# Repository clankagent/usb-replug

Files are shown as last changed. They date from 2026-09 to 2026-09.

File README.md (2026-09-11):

# USB Replug — revision B

A USB-A male-to-female adapter intended to simulate unplugging and reconnecting a USB 2.0 peripheral with one button press. A CMOS 555 provides the delay; there is no microcontroller or firmware.

**Public design review. Unbuilt prototype; not ready to order.** Assembly placement mappings remain unresolved and hardware performance has not been tested. This repository contains only the current revision B source and review material, not previous design iterations or fabrication releases.

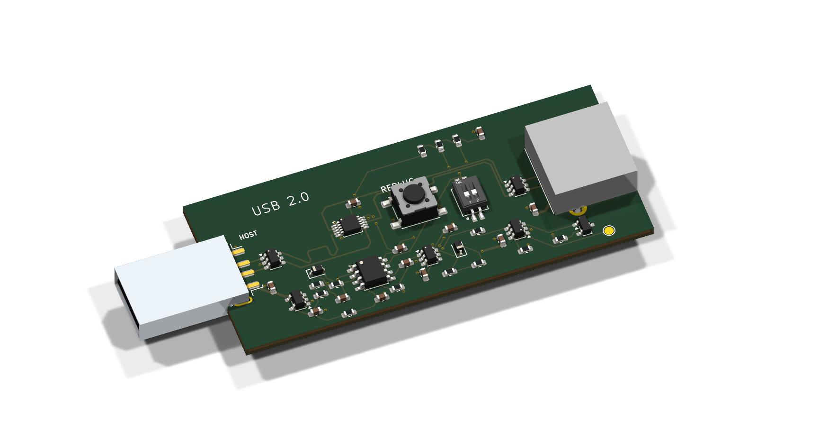
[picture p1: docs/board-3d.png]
Revision B KiCad render


[Schematic PDF](docs/schematic.pdf) · [3D STEP model](docs/usb-replug.step) · [BOM](bom.csv) · [Remaining work](docs/STATUS.md)

## Intended operation

Press the central button to disconnect device VBUS and both data lines, then reconnect automatically. Ground and shields stay connected. The trigger circuit is intended to let the timer expire even when the button remains held down.

| Two-position DIP switch | Approximate off time |
|---|---:|
| Both OFF | 3 seconds |
| Either ON | 2 seconds |
| Both ON | 1 second |

Change the DIP settings while idle. RC tolerance, leakage and capacitor bias affect timing; these are nominal settings, not calibrated delays.

## Open the design

Open `usb-replug.kicad_pro` in KiCad 10. The root schematic links three functional sheets. The PCB, footprints and referenced STEP models are included with project-relative paths. Official symbols are embedded in the schematics; the custom symbol library is under `libraries/`.

The board is 70 × 30 mm with four copper layers and nominal 1.6 mm thickness. Its fabrication target is JLC04161H-7628, outer 1 oz / inner 0.5 oz copper, green mask, white silkscreen and lead-free HASL. The male connector overhangs the PCB edge. A different manufacturer needs a stackup and assembly review.

## Validation

The packaged source was checked with KiCad 10.0.6: no reported ERC, PCB DRC, unconnected-item or schematic-parity findings. Reports and their configured ignored-check lists are included in `docs/checks/`. This is not a claim that every possible rule is enabled or that hardware works.

The intended USB data rate is up to 480 Mbps. Signal integrity, impedance, interoperability, ESD behavior, loaded voltage drop and timing still require review and physical testing. Length matching alone does not validate the USB routing; the layout includes uncoupled breakout sections. A self-powered peripheral may disconnect logically without actually power-cycling. Host power budget includes the adapter's own consumption.

## Assembly and availability

All small components are intended for factory assembly. JLCPCB's quoted Economic option excluded J1, the male connector; it has accessible surface-mount signal joints plus shell mounting joints. J2 is through-hole. The quoted Standard option included both connectors. Historical September 2026 batch estimates were $71.08 and $106.07 respectively for five PCBs with two populated, excluding shipping and tax. These are not current offers or endorsements.

Gerbers and pick-and-place files are deliberately absent: the previous assembler preview exposed rotation and connector-origin mismatches. No order-ready release has been published and no board has been ordered.

## Licensing and provenance

See [THIRD_PARTY.md](THIRD_PARTY.md). Public visibility does not grant an open-source license for the original project; no project license has been selected. Existing third-party licenses remain in effect. Provenance and redistribution permissions for the imported footprints and DIP-switch model remain unresolved; see the linked notes.

Prepared with AI-assisted design and review; the KiCad files, not an image, are the design source of truth.

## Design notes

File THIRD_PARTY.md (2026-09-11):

# Third-party material and licensing status

## Official KiCad libraries

Official embedded symbol definitions, the named official footprint libraries, and standard package STEP models come from the KiCad 10 installation. They are compiled by the KiCad community and distributed under CC-BY-SA 4.0 with the KiCad electronic-design exception. The retained [KiCad license notice](libraries/KiCad-LICENSE.md) explains the exception and the separate rules for redistributed library collections.

Sources: https://www.kicad.org/libraries/ and https://gitlab.com/kicad/libraries/

Official footprint copies use project-relative model paths. The `ReplugB` library is custom/imported material, not an official KiCad library, despite the generic description in the library table.

## Connector models

`models/Connector_USB.3dshapes/USB_A_Molex_48037-2200_Horizontal.step` is an original simplified, drawing-based model, not manufacturer-exact CAD. Reference: Molex 480372200 sales drawing, https://www.molex.com/content/dam/molex/molex-dot-com/products/automated/en-us/salesdrawingpdf/480/48037/480372200_sd.pdf

`models/ReplugB.3dshapes/Jingtuo_902-131A1011D10100.step` is an original simplified, drawing-based model. Supplier-linked CAD with a mismatched envelope was rejected. Reference: https://www.lcsc.com/product-detail/C2345.html

Both simplify contacts and stamped/internal details; do not assume full enclosure clearance or mating fidelity from the render alone.

## Imported DIP model and corrected footprints

`models/ReplugB.3dshapes/SHOUHAN_1.27-2P_TPPT.step` was imported from supplier-linked CAD and offset vertically to align with the board. Reference part: https://www.lcsc.com/product-detail/C7421516.html . A redistribution license has not been established. The two `ReplugB.pretty` footprints were imported and corrected against those manufacturers' drawings, including pad and drill dimensions. Their source licensing also needs review before public distribution.

The repository is publicly viewable, but these permissions remain unresolved. Inclusion does not establish a redistribution license. The assembled STEP export and render also include the imported model.

## Original design

No public license is selected yet for the original circuit, layout, documentation or drawing-based models. Public visibility does not waive third-party rights or grant an open-source license. Supplier datasheet PDFs and rejected/unused CAD are not bundled; use the source links and BOM references.

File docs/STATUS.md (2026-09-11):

# Review status

Revision B is a publicly viewable, unbuilt prototype snapshot. No fabrication or assembly release is approved.

## Before a prototype fabrication release

- Verify every assembler-specific rotation, pin-one/cathode orientation and placement origin. The earlier JLC preview showed timer rotation and connector position/orientation mismatches. Browser placement edits were exploratory and are not a validated CPL.
- Review USB differential routing, breakout coupling and stackup impedance. Trace length matching is insufficient.
- Review connector mechanical fit, overhang and assembly fixture requirements.
- Review component ratings, current limit, power-budget behavior and peripheral discharge/reconnect behavior against the selected BOM.
- Regenerate fabrication and placement files from the reviewed native revision; inspect the target assembler's complete preview and DFM results.

## Licensing work still unresolved

- Resolve the license of the supplier-linked SHOUHAN DIP-switch STEP model, or replace it with a newly constructed drawing-based model.
- Review provenance/licensing of the two imported, corrected `ReplugB` footprints. The manufacturer dimensions were checked, but the importer source does not by itself establish redistribution permission.
- Choose a project hardware/documentation license. Retain KiCad's library notice and applicable attribution.

## After building prototypes

Measure disconnect/reconnect timing, held-button behavior, loaded voltage drop, current limit and residual device power. Test representative USB low/full/high-speed devices and self-powered peripherals. Validate USB signal quality and protection behavior before claiming tested 480 Mbps operation or production readiness.

## Included checks

KiCad ERC and DRC/parity were rerun after copying the source into this repository. See `checks/`. The reports disclose ignored rule categories; no new suppressions were introduced for packaging.

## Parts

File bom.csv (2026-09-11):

Reference | Value | Manufacturer | MPN | LCSC | Footprint | Datasheet | Notes
J1 | USB-A PLUG | Molex | 480372200 | C2765195 | Connector_USB:USB_A_Molex_48037-2200_Horizontal | https://www.molex.com/content/dam/molex/molex-dot-com/products/automated/en-us/salesdrawingpdf/480/48037/480372200_sd.pdf | ; JLCPCB Standard assembly only. Economic variant leaves this connector unpopulated.
J2 | USB-A SOCKET | Jingtuo | 902-131A1011D10100 | C2345 | ReplugB:Jingtuo_902-131A1011D10100 | https://www.lcsc.com/datasheet/C2345.pdf | USB-A female, 1.5A/30V; 0.9mm signal drills and 2.1mm shell drills per manufacturer drawing
U1 | TPS2552DBVR | Texas Instruments | TPS2552DBVR | C46506 | Package_TO_SOT_SMD:SOT-23-6 | https://www.ti.com/lit/ds/symlink/tps2552.pdf
U2 | TLV75533PDBVR | Texas Instruments | TLV75533PDBVR | C404027 | Package_TO_SOT_SMD:SOT-23-5 | https://www.ti.com/lit/ds/symlink/tlv755p.pdf
U3 | TS3USB30EDGSR | Texas Instruments | TS3USB30EDGSR | C131998 | Package_SO:MSOP-10_3x3mm_P0.5mm | https://www.ti.com/lit/ds/symlink/ts3usb30e.pdf
U4 | TLC555CDR | Texas Instruments | TLC555CDR | C6986 | Package_SO:SOIC-8_3.9x4.9mm_P1.27mm | https://www.ti.com/lit/ds/symlink/tlc555.pdf | CMOS monostable; C6986; no firmware; approximately 1/2/3 seconds
U6 | SN74LVC2G14DBVR | Texas Instruments | SN74LVC2G14DBVR | C12401 | Package_TO_SOT_SMD:SOT-23-6 | https://www.ti.com/lit/ds/symlink/sn74lvc2g14.pdf
D1 | USBLC6-2SC6 | STMicroelectronics | USBLC6-2SC6 | C7519 | Package_TO_SOT_SMD:SOT-23-6 | https://www.st.com/resource/en/datasheet/usblc6-2.pdf
D2 | USBLC6-2SC6 | STMicroelectronics | USBLC6-2SC6 | C7519 | Package_TO_SOT_SMD:SOT-23-6 | https://www.st.com/resource/en/datasheet/usblc6-2.pdf
D3 | BAT54WS | Diodes Incorporated | BAT54WS-7-F | C124205 | Diode_SMD:D_SOD-323 | https://www.diodes.com/datasheet/download/BAT54WS.pdf | Fast RC discharge; pin 1 cathode; SOD323 two-pin package
Q1 | BSS138 | onsemi | BSS138LT1G | C82045 | Package_TO_SOT_SMD:SOT-23 | https://www.onsemi.com/pdf/datasheet/bss138lt1-d.pdf
SW1 | REPLUG | C&K | PTS645SM43SMTR92 LFS | C221880 | Button_Switch_SMD:SW_SPST_PTS645Sx43SMTR92 | https://www.ckswitches.com/media/1471/pts645.pdf
SW2 | DELAY SELECT | SHOUHAN | 1.27-2P TPPT | C7421516 | ReplugB:SHOUHAN_1.27-2P_TPPT | https://www.lcsc.com/datasheet/C7421516.pdf | 24V 25mA. Switch only while idle. OFF/OFF ~3s; one ON ~2s; both ON ~1s.
R1 | 45.3k | Yageo | RC0603FR-0745K3L | C245971 | Resistor_SMD:R_0603_1608Metric | https://www.yageo.com/upload/media/product/productsearch/datasheet/rchip/PYu-RC_Group_51_RoHS_L_12.pdf | Current limit approx 0.57 A; intended device load <=500mA with host budget respected
R2 | 100k | UNI-ROYAL | 0603WAF1003T5E | C25803 | Resistor_SMD:R_0603_1608Metric | https://www.lcsc.com/datasheet/C25803.pdf | 1%, 0.1 W, 0603
R3 | 100k | UNI-ROYAL | 0603WAF1003T5E | C25803 | Resistor_SMD:R_0603_1608Metric | https://www.lcsc.com/datasheet/C25803.pdf | 1%, 0.1 W, 0603
R4 | 1k | UNI-ROYAL | 0603WAF1001T5E | C21190 | Resistor_SMD:R_0603_1608Metric | https://www.lcsc.com/datasheet/C21190.pdf | Limits trigger clamp current
R5 | 1M | UNI-ROYAL | 0603WAF1004T5E | C22935 | Resistor_SMD:R_0603_1608Metric | https://www.lcsc.com/datasheet/C22935.pdf | 1%, 0603; t nominal = ln(3) RC; timing accuracy intentionally approximate
R6 | 1M | UNI-ROYAL | 0603WAF1004T5E | C22935 | Resistor_SMD:R_0603_1608Metric | https://www.lcsc.com/datasheet/C22935.pdf | 1%, 0603; t nominal = ln(3) RC; timing accuracy intentionally approximate
R7 | 1M | UNI-ROYAL | 0603WAF1004T5E | C22935 | Resistor_SMD:R_0603_1608Metric | https://www.lcsc.com/datasheet/C22935.pdf | 1%, 0603; t nominal = ln(3) RC; timing accuracy intentionally approximate
R8 | 100k | UNI-ROYAL | 0603WAF1003T5E | C25803 | Resistor_SMD:R_0603_1608Metric | https://www.lcsc.com/datasheet/C25803.pdf | Power-on reset pull-up
R9 | 100k | UNI-ROYAL | 0603WAF1003T5E | C25803 | Resistor_SMD:R_0603_1608Metric | https://www.lcsc.com/datasheet/C25803.pdf | Button pull-up
R15 | 47k | UNI-ROYAL | 0603WAF4702T5E | C25819 | Resistor_SMD:R_0603_1608Metric | https://www.lcsc.com/datasheet/C25819.pdf | 1%, 0.1 W, 0603
R16 | 1k | UNI-ROYAL | 0603WAF1001T5E | C21190 | Resistor_SMD:R_0603_1608Metric | https://www.lcsc.com/datasheet/C21190.pdf | 1%, 0.1 W, 0603
R17 | 1k | UNI-ROYAL | 0603WAF1001T5E | C21190 | Resistor_SMD:R_0603_1608Metric | https://www.lcsc.com/datasheet/C21190.pdf | 1%, 0.1 W, 0603
R18 | 100k | UNI-ROYAL | 0603WAF1003T5E | C25803 | Resistor_SMD:R_0603_1608Metric | https://www.lcsc.com/datasheet/C25803.pdf | 1%, 0.1 W, 0603
C1 | 1uF | Samsung Electro-Mechanics | CL10A105KB8NNNC | C15849 | Capacitor_SMD:C_0603_1608Metric | https://www.lcsc.com/datasheet/C15849.pdf | X7R, 16V, 0603; 1uF and 100nF bypass capacitors; 50V, +/-10%, X5R; supplier Basic part
C2 | 1uF | Samsung Electro-Mechanics | CL10A105KB8NNNC | C15849 | Capacitor_SMD:C_0603_1608Metric | https://www.lcsc.com/datasheet/C15849.pdf | X7R, 16V, 0603; 1uF and 100nF bypass capacitors; 50V, +/-10%, X5R; supplier Basic part
C3 | 1uF | Samsung Electro-Mechanics | CL10A105KB8NNNC | C15849 | Capacitor_SMD:C_0603_1608Metric | https://www.lcsc.com/datasheet/C15849.pdf | X7R, 16V, 0603; 1uF and 100nF bypass capacitors; 50V, +/-10%, X5R; supplier Basic part
C4 | 100nF | YAGEO | CC0603KRX7R9BB104 | C14663 | Capacitor_SMD:C_0603_1608Metric | https://www.lcsc.com/datasheet/C14663.pdf | X7R, 16V, 0603; 1uF and 100nF bypass capacitors; 50V, +/-10%, X7R; supplier Basic part
C5 | 100nF | YAGEO | CC0603KRX7R9BB104 | C14663 | Capacitor_SMD:C_0603_1608Metric | https://www.lcsc.com/datasheet/C14663.pdf | X7R, 16V, 0603; 1uF and 100nF bypass capacitors; 50V, +/-10%, X7R; supplier Basic part
C6 | 100nF | YAGEO | CC0603KRX7R9BB104 | C14663 | Capacitor_SMD:C_0603_1608Metric | https://www.lcsc.com/datasheet/C14663.pdf | X7R, 16V, 0603; 1uF and 100nF bypass capacitors; 50V, +/-10%, X7R; supplier Basic part
C7 | 100nF | YAGEO | CC0603KRX7R9BB104 | C14663 | Capacitor_SMD:C_0603_1608Metric | https://www.lcsc.com/datasheet/C14663.pdf | 555 control-voltage bypass; 50V, +/-10%, X7R; supplier Basic part
C8 | 100nF | YAGEO | CC0603KRX7R9BB104 | C14663 | Capacitor_SMD:C_0603_1608Metric | https://www.lcsc.com/datasheet/C14663.pdf | X7R, 16V, 0603; 1uF and 100nF bypass capacitors; 50V, +/-10%, X7R; supplier Basic part
C9 | 100nF | YAGEO | CC0603KRX7R9BB104 | C14663 | Capacitor_SMD:C_0603_1608Metric | https://www.lcsc.com/datasheet/C14663.pdf | AC-coupled falling-edge trigger: reconnects even with button held; 50V, +/-10%, X7R; supplier Basic part
C10 | 1uF | Samsung Electro-Mechanics | CL10A105KB8NNNC | C15849 | Capacitor_SMD:C_0603_1608Metric | https://www.lcsc.com/datasheet/C15849.pdf | X7R, 16V, 0603; 1uF and 100nF bypass capacitors; 50V, +/-10%, X5R; supplier Basic part
TP1 | FAULT_N | PCB | PCB pad |  | TestPoint:TestPoint_Pad_D1.5mm |  | Diagnostic pad; no purchased component
C11 | 1uF | Samsung Electro-Mechanics | CL10A105KB8NNNC | C15849 | Capacitor_SMD:C_0603_1608Metric | https://www.lcsc.com/datasheet/C15849.pdf | 1uF X5R 50V; nominal capacitance changes with DC bias and temperature; 50V, +/-10%, X5R; supplier Basic part
C12 | 1uF | Samsung Electro-Mechanics | CL10A105KB8NNNC | C15849 | Capacitor_SMD:C_0603_1608Metric | https://www.lcsc.com/datasheet/C15849.pdf | 1uF X5R 50V; nominal capacitance changes with DC bias and temperature; 50V, +/-10%, X5R; supplier Basic part
D4 | BAT54WS | Diodes Incorporated | BAT54WS-7-F | C124205 | Diode_SMD:D_SOD-323 | https://www.diodes.com/datasheet/download/BAT54WS.pdf | Positive trigger clamp on button release; cathode at V3V3

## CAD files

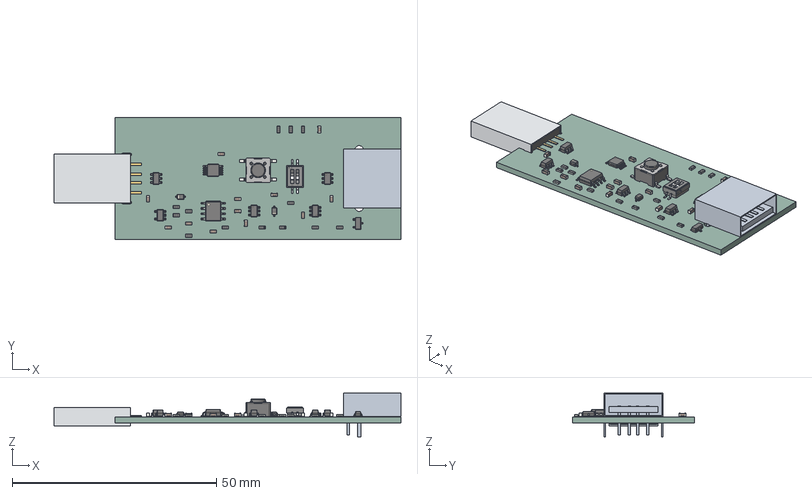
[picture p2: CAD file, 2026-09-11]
docs/usb-replug.step
85.0 x 30.0 x 10.7 mm
R_0603_1608Metric x 13
D_SOD-323 x 2
SOT-23-6 x 4
MSOP-10_3x3mm_P0.5mm
SOT-23
C_0603_1608Metric x 12
Nickel_shell
Insulator
Contact_1
Contact_2
Contact_3
Contact_4
Peg_-2.25
Peg_2.25
SOT-23-5
SOIC-8_3.9x4.9mm_P1.27mm
SW_SPST_PTS645Sx43SMTR92
SW-SMD_2P-L5.4-W4.1-P1.27-LS8.4
usb-replug_PCB

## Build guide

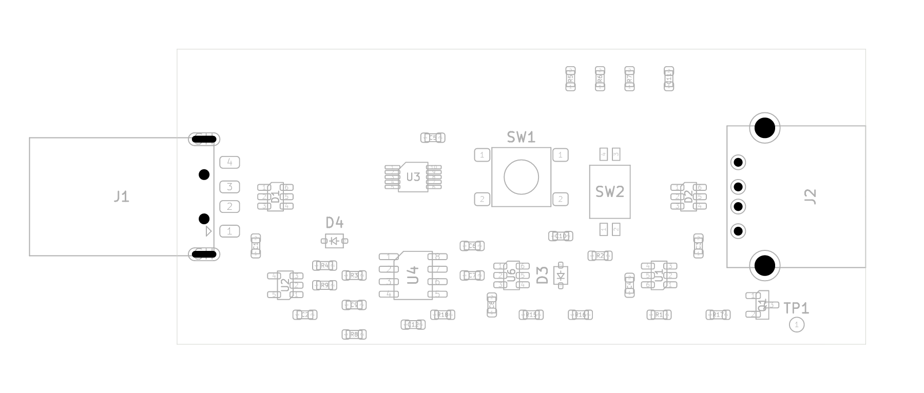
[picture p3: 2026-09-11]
docs/assembly-top.png

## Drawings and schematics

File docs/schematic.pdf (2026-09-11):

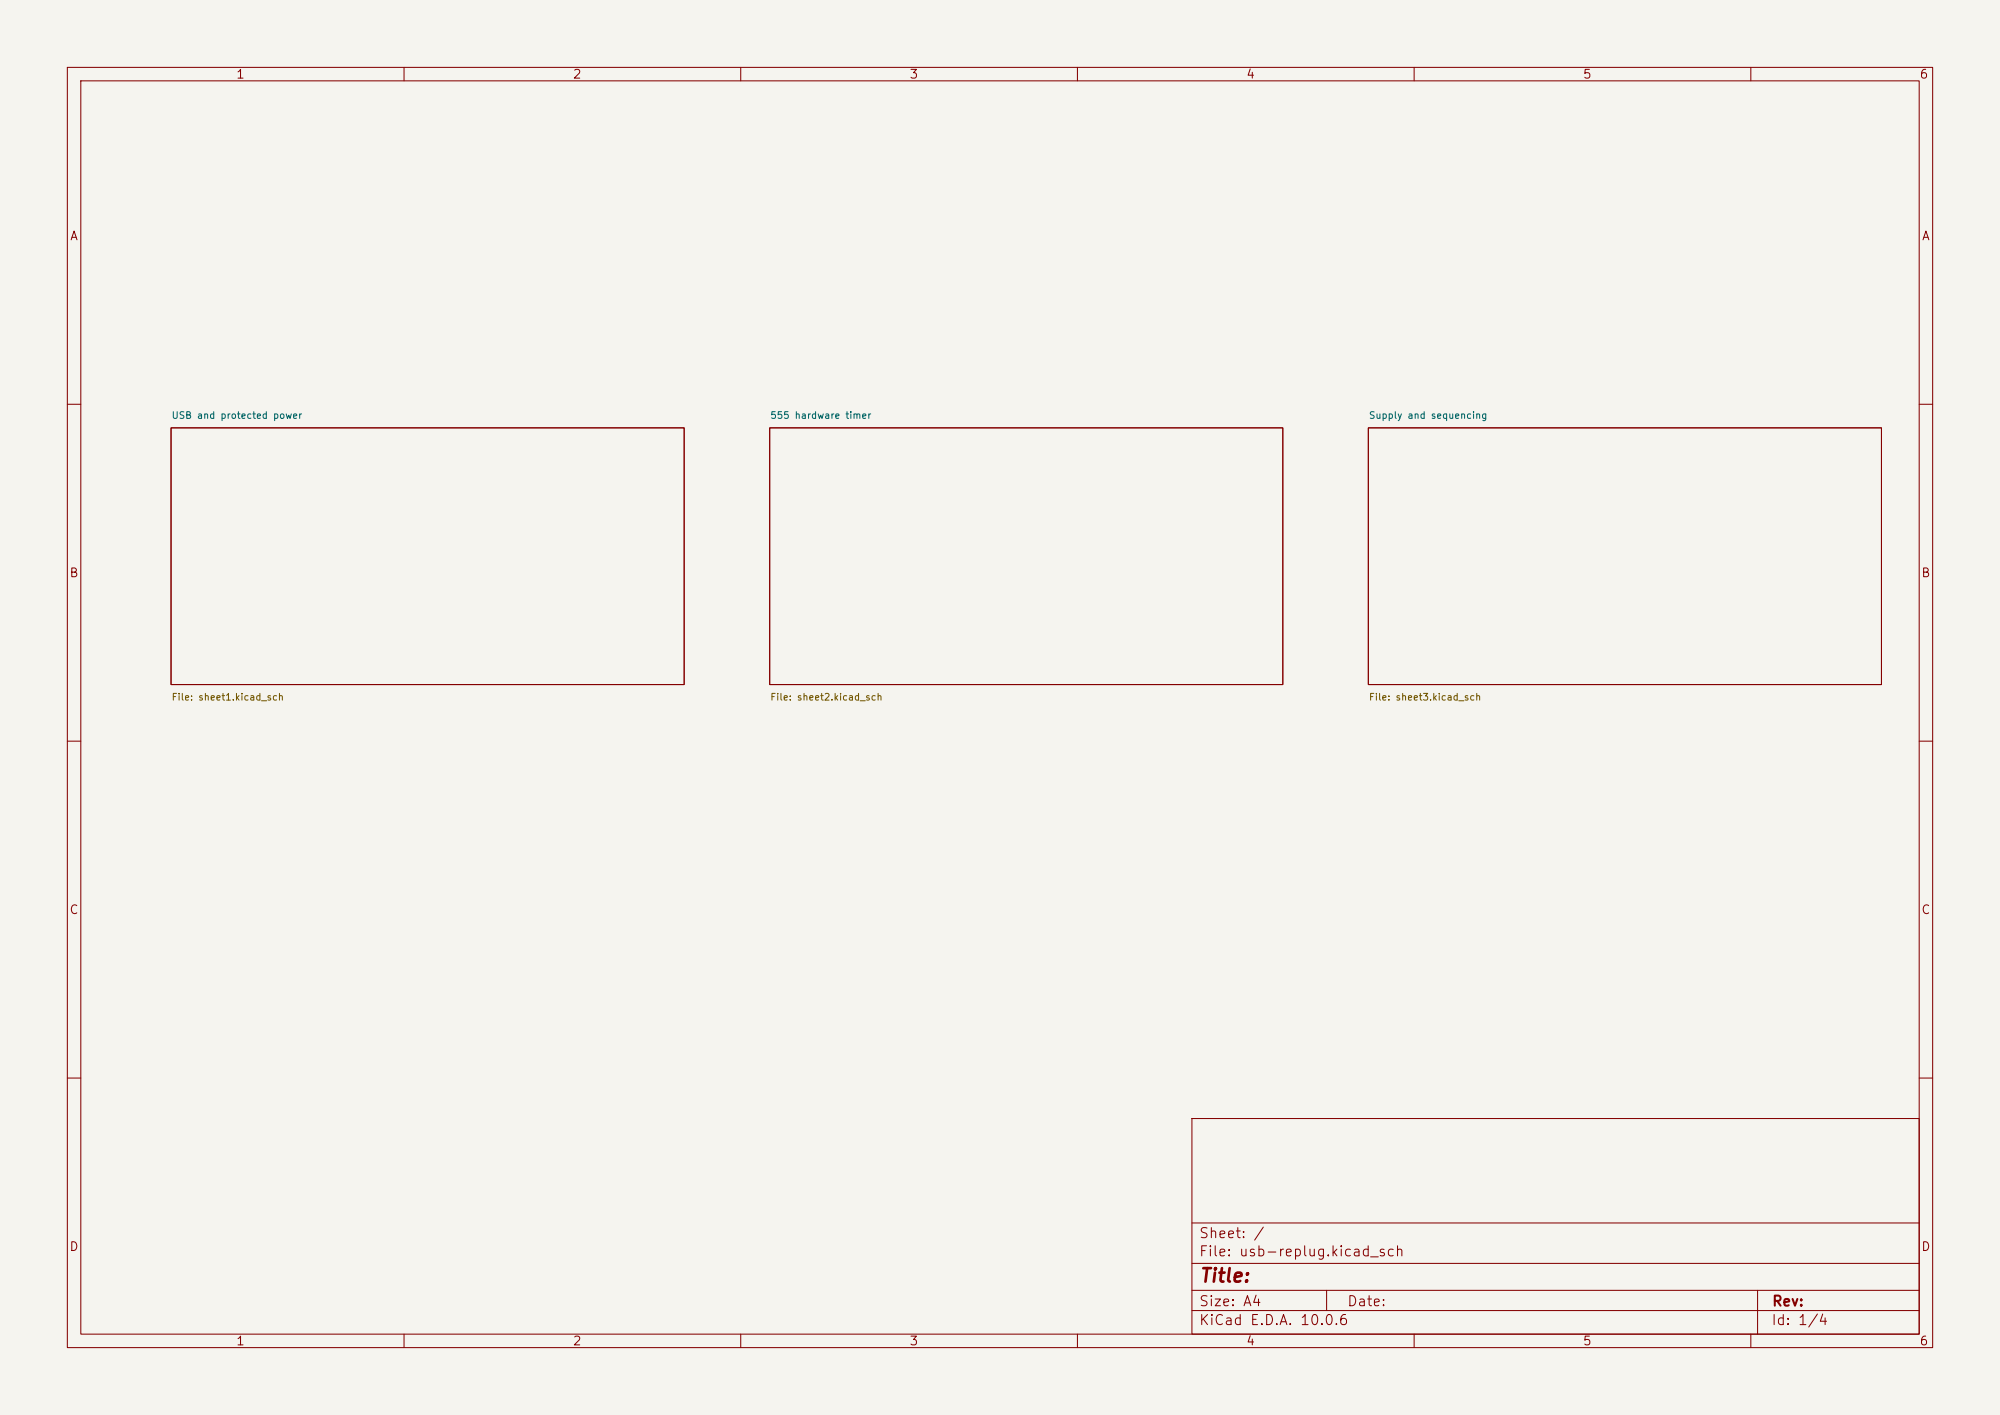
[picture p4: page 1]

Size: A4 | Rev:
KiCad E.D.A. 10.0.6 | Id: 1/4

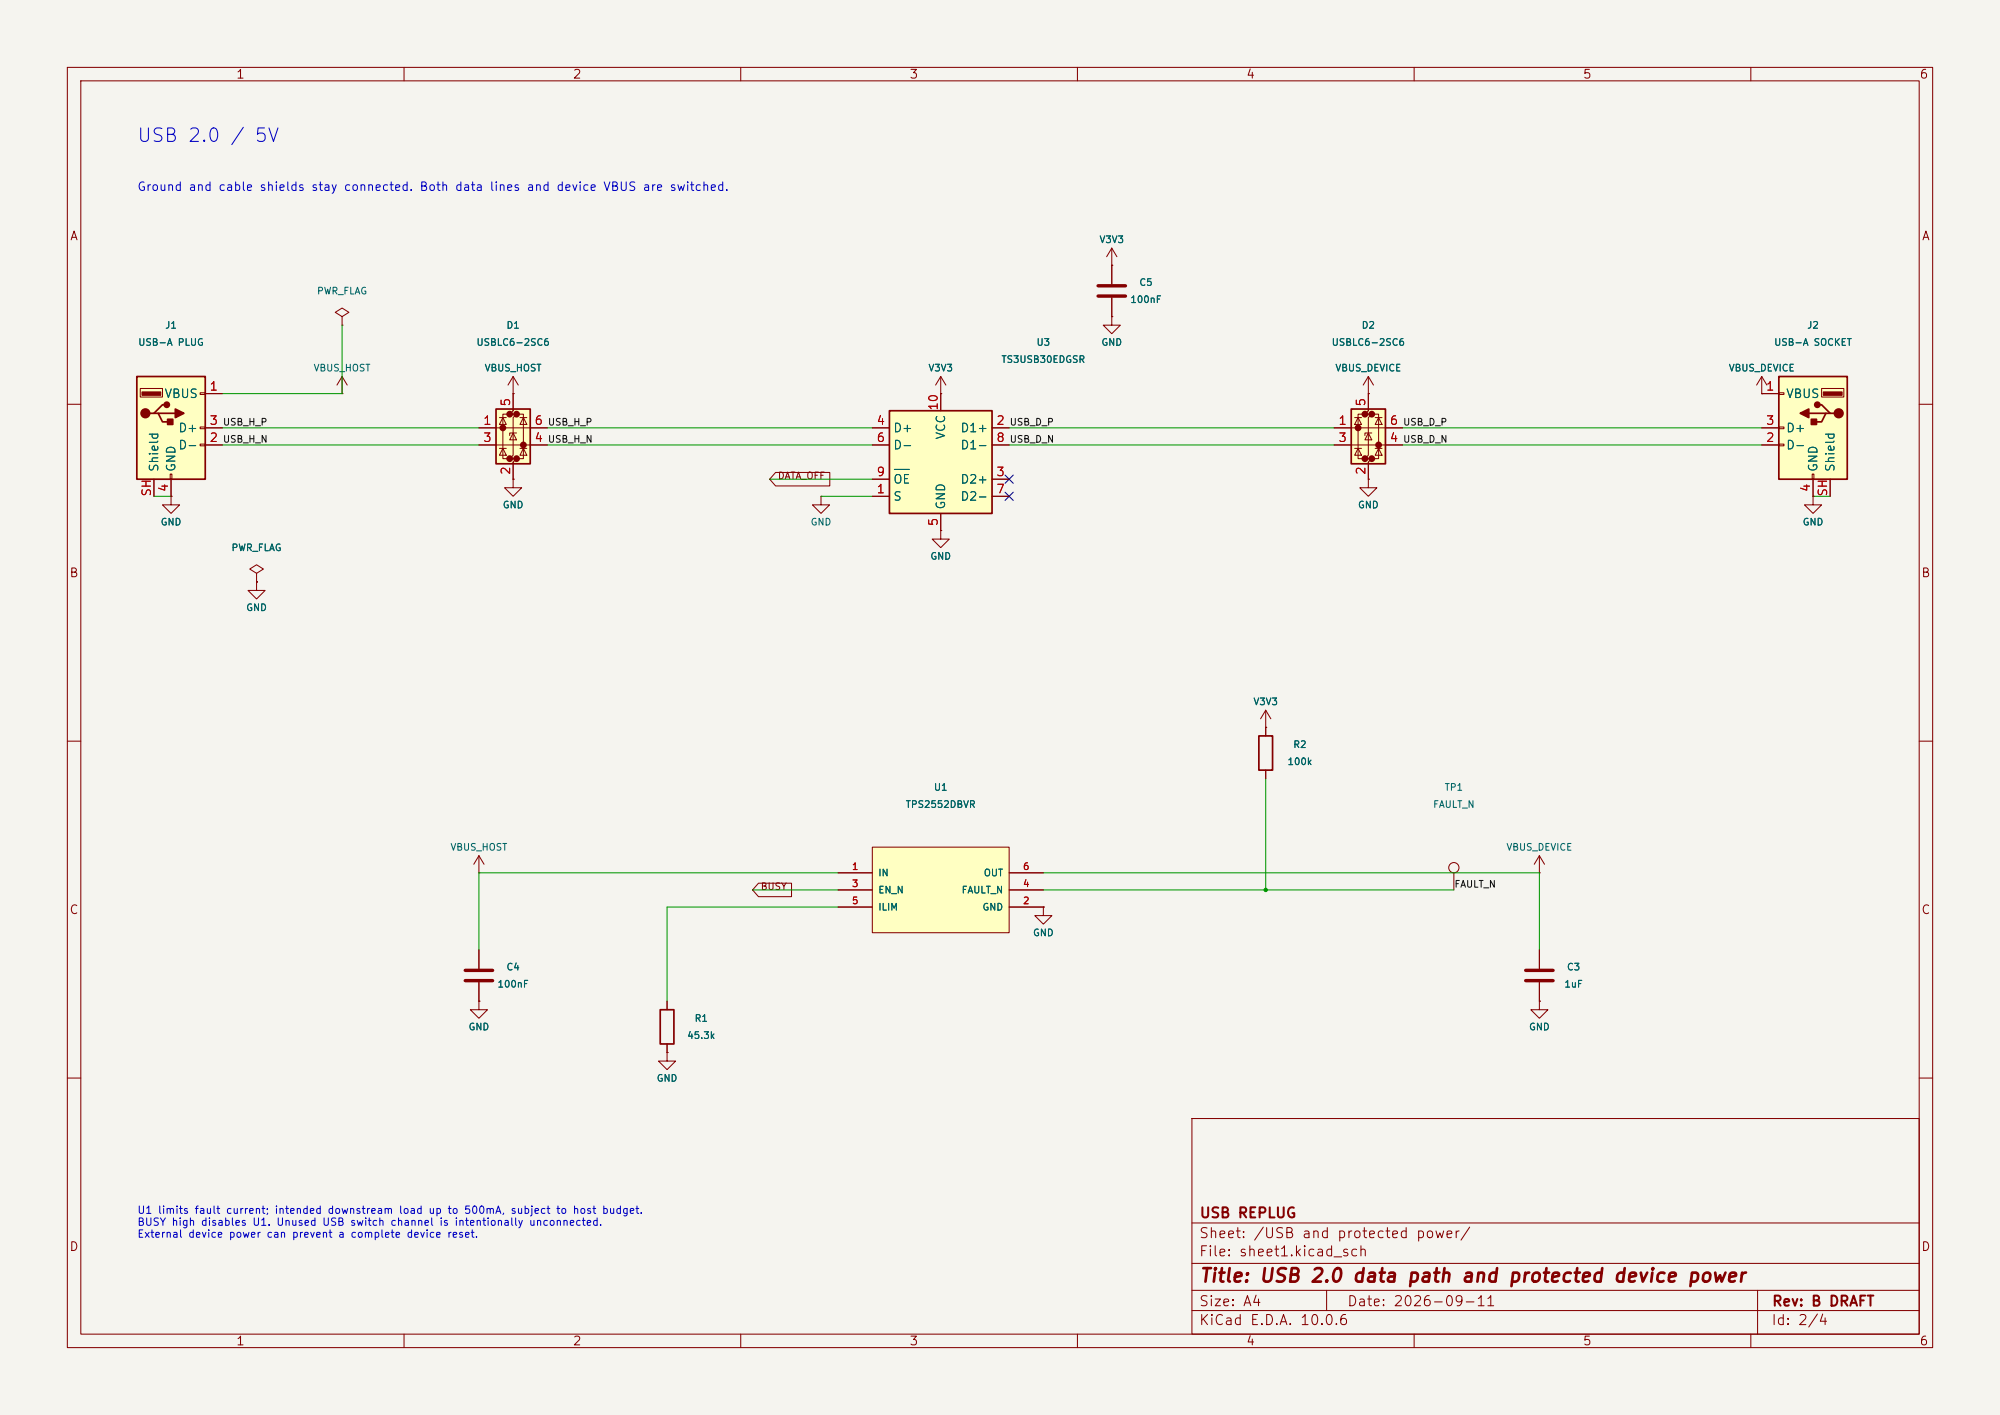
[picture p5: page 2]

Ground and cable shields stay connected. Both data lines and device VBUS are switched.

U1 limits fault current; intended downstream load up to 500mA, subject to host budget. BUSY high disables U1. Unused USB switch channel is intentionally unconnected. External device power can prevent a complete device reset.

USB REPLUG
Sheet: /USB and protected power/
File: sheet1.kicad_sch
Title: USB 2.0 data path and protected device power

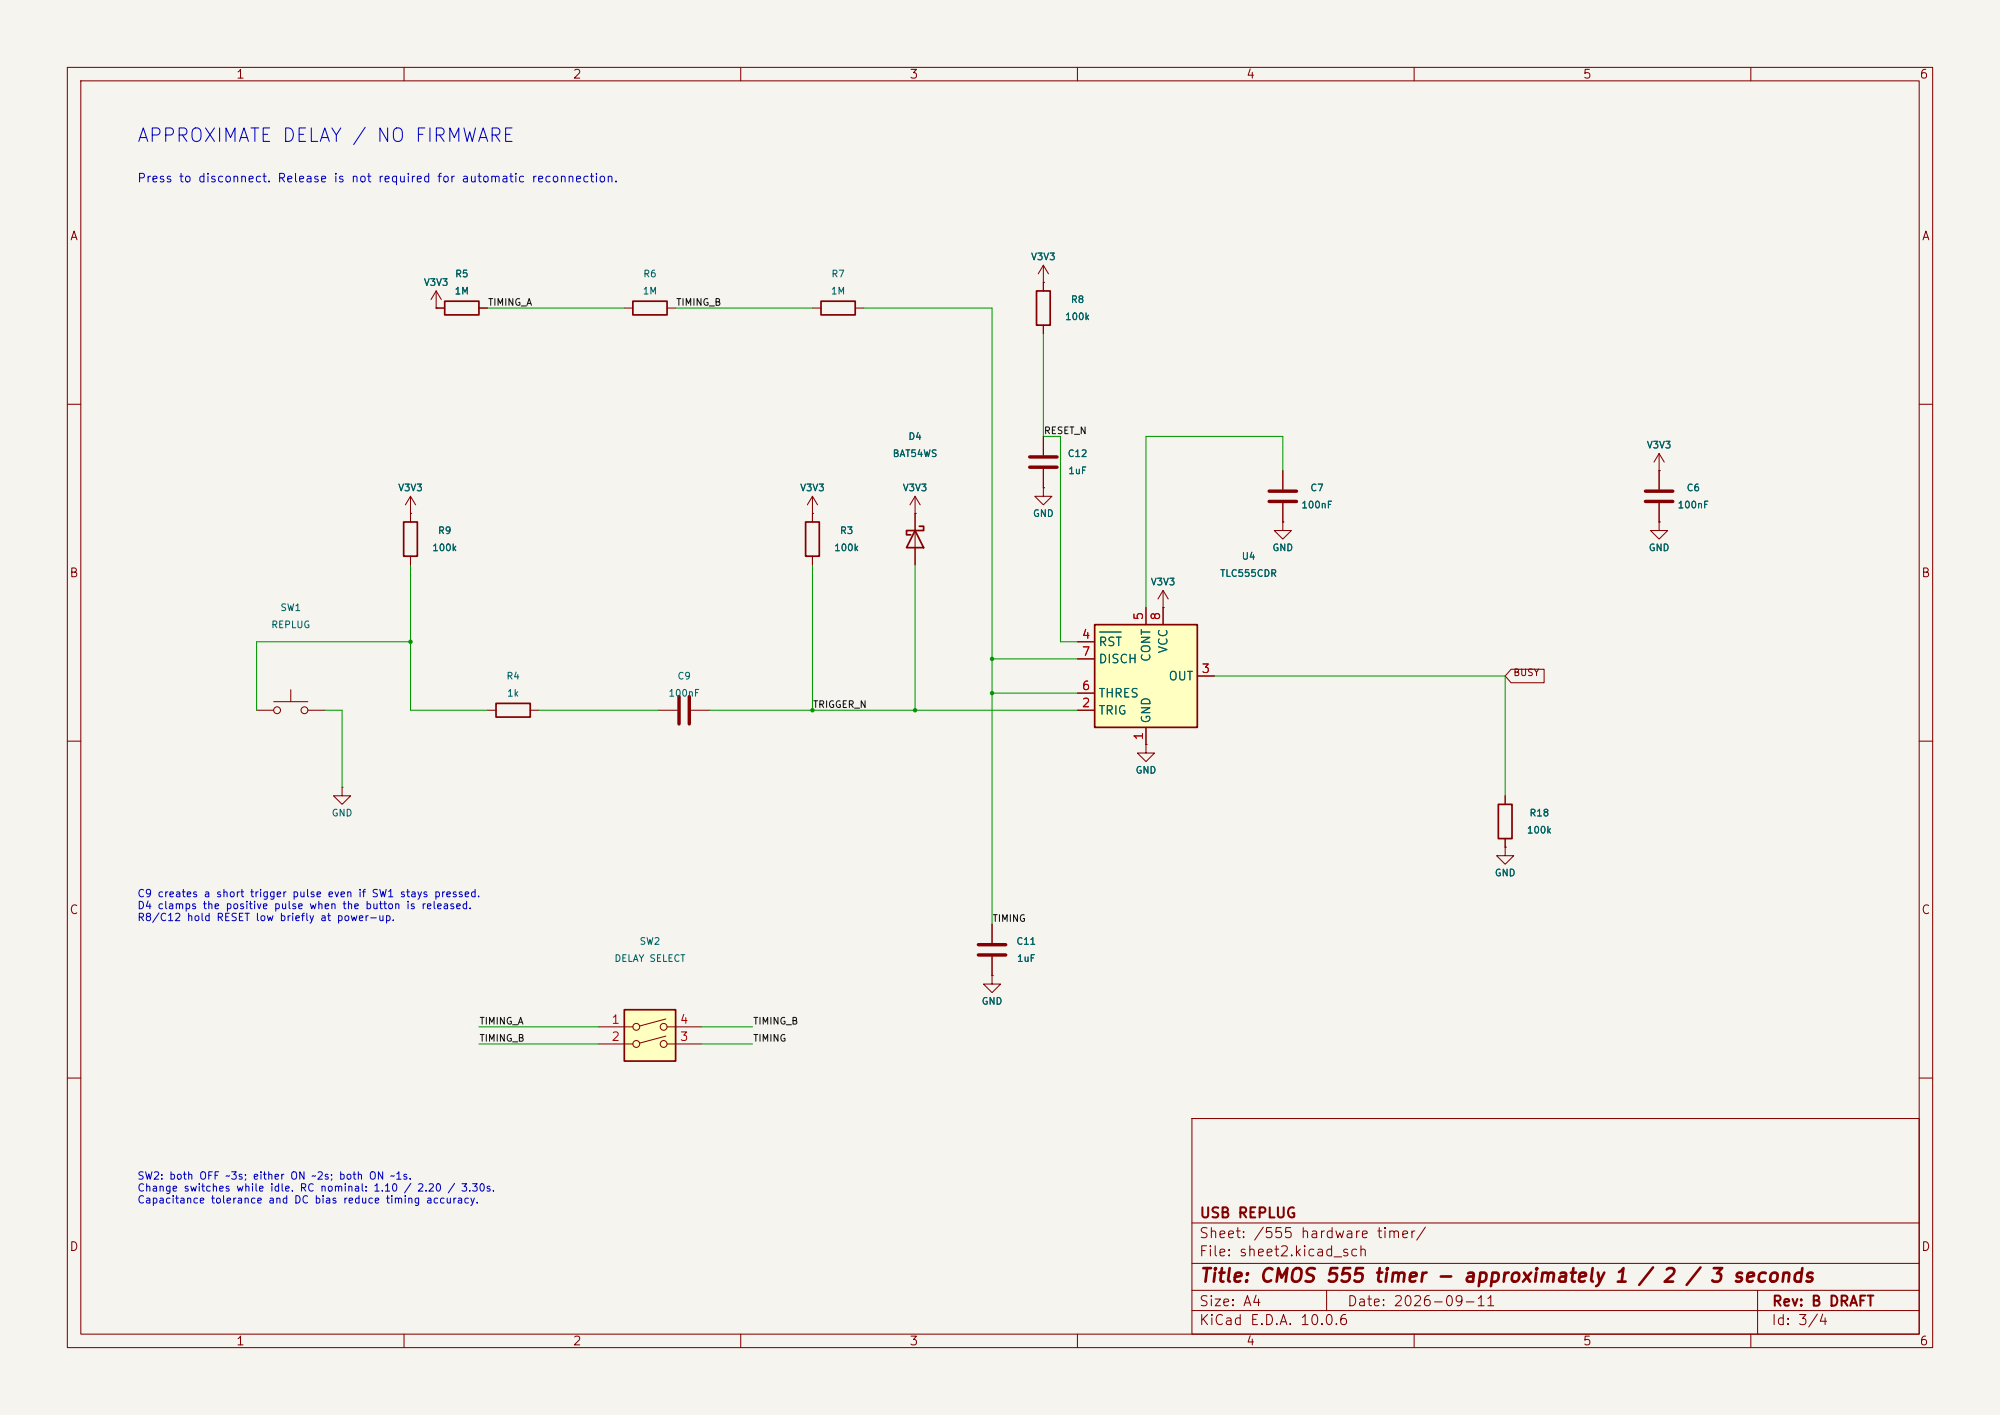
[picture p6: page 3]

USB REPLUG
Sheet: /555 hardware timer/
File: sheet2.kicad_sch
Title: CMOS 555 timer - approximately 1 / 2 / 3 seconds

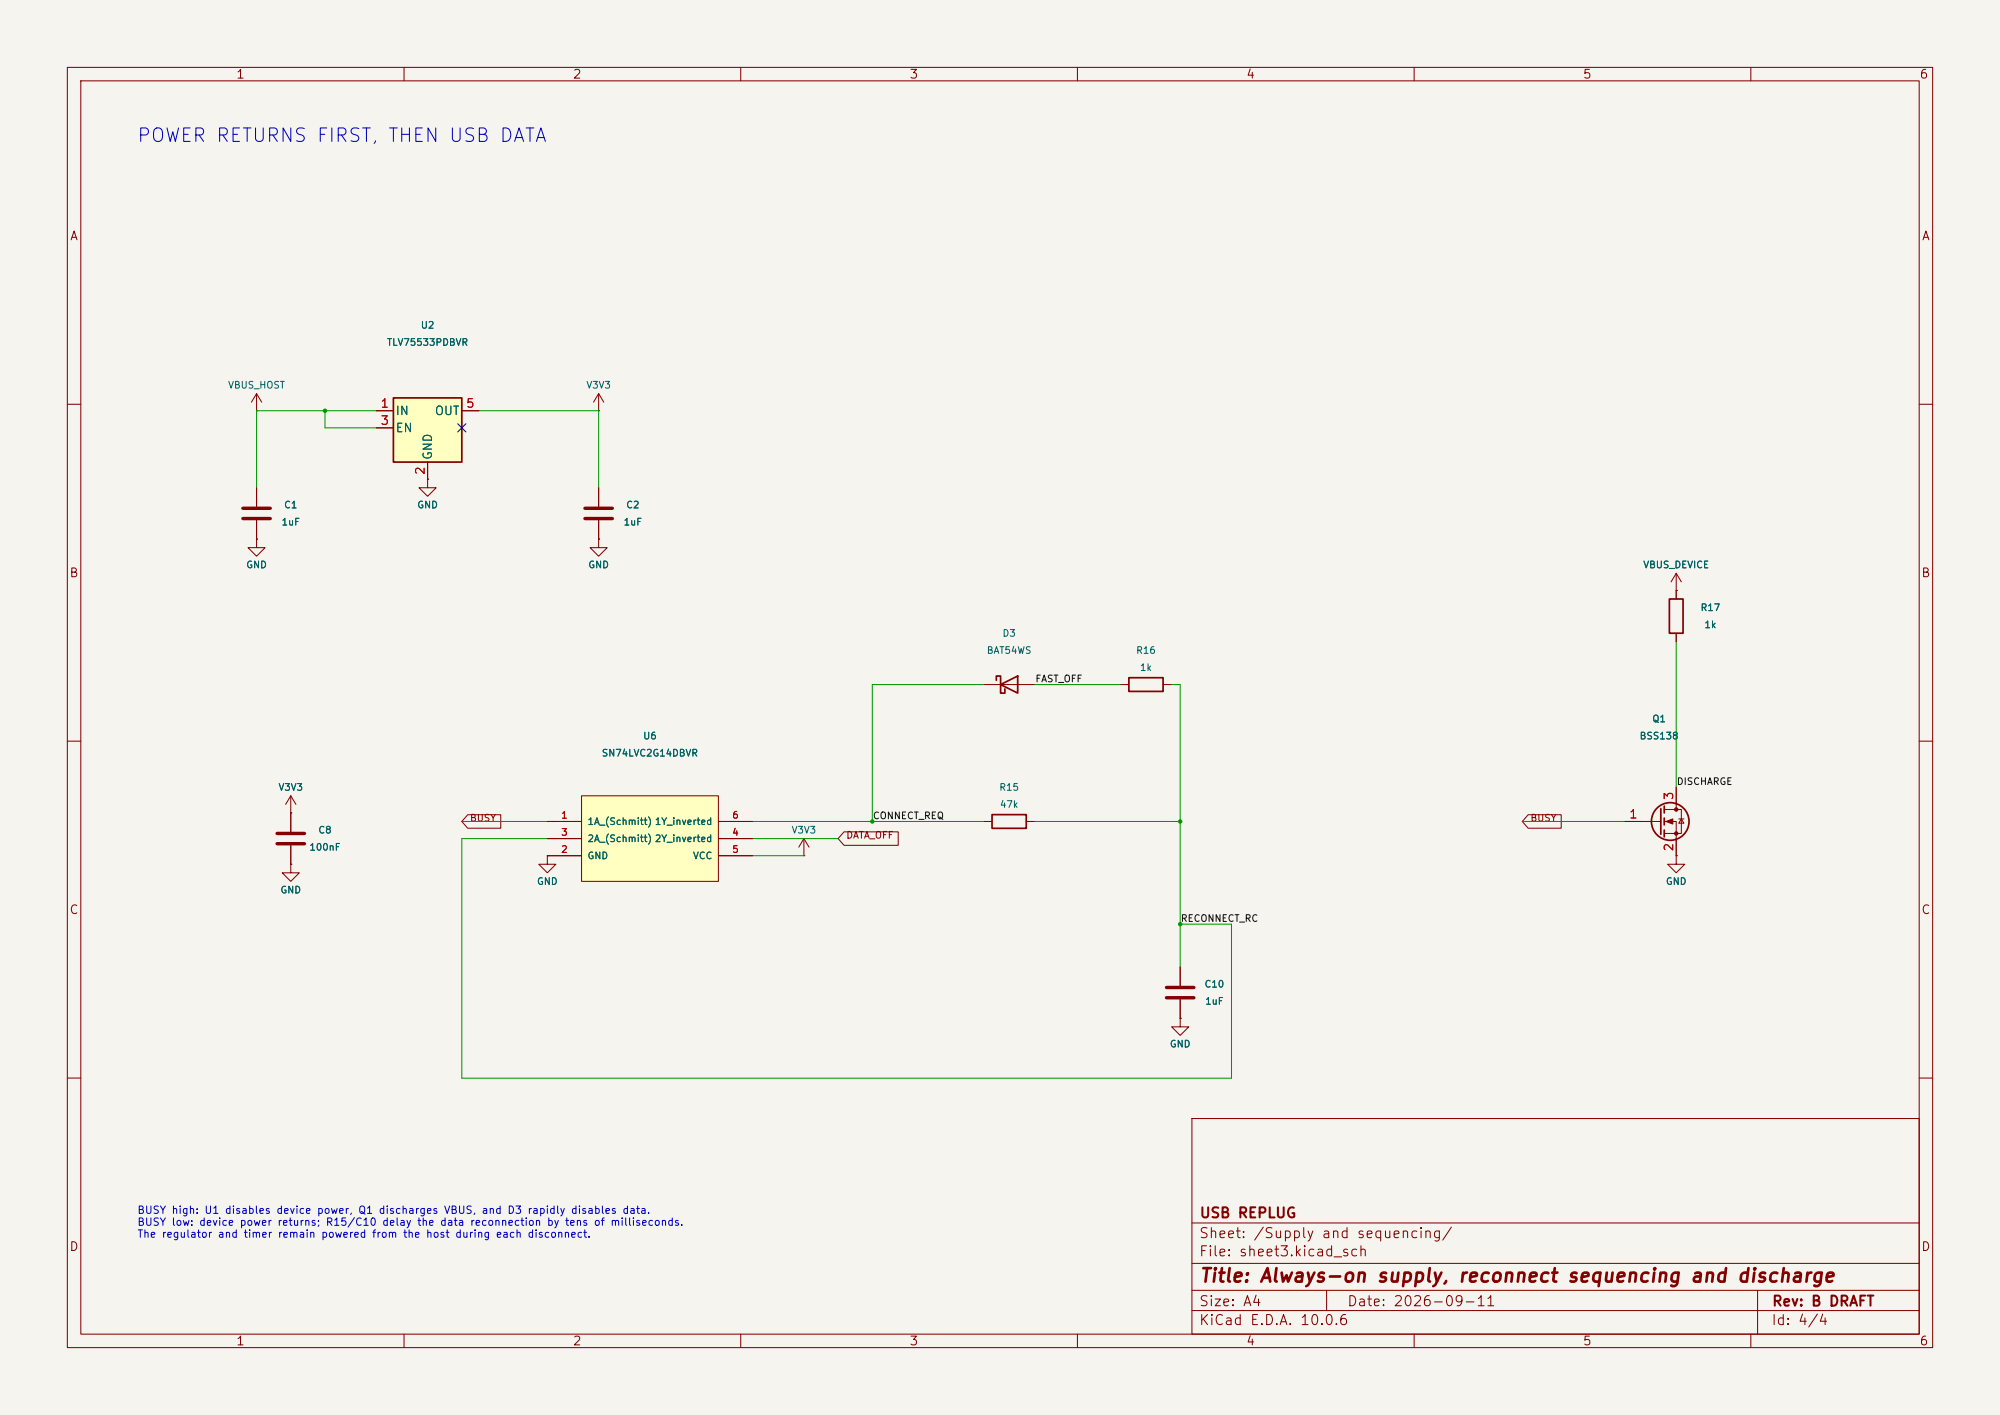
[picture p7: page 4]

POWER RETURNS FIRST, THEN USB DATA

CONNECT_REQ BUSY high: U1 disables device power, Q1 discharges VBUS, and D3 rapidly disables data. BUSY low: device power returns; R15/C10 delay the data reconnection by tens of milliseconds. The regulator and timer remain powered from the host during each disconnect.

USB REPLUG
Sheet: /Supply and sequencing/
File: sheet3.kicad_sch
Title: Always-on supply, reconnect sequencing and discharge

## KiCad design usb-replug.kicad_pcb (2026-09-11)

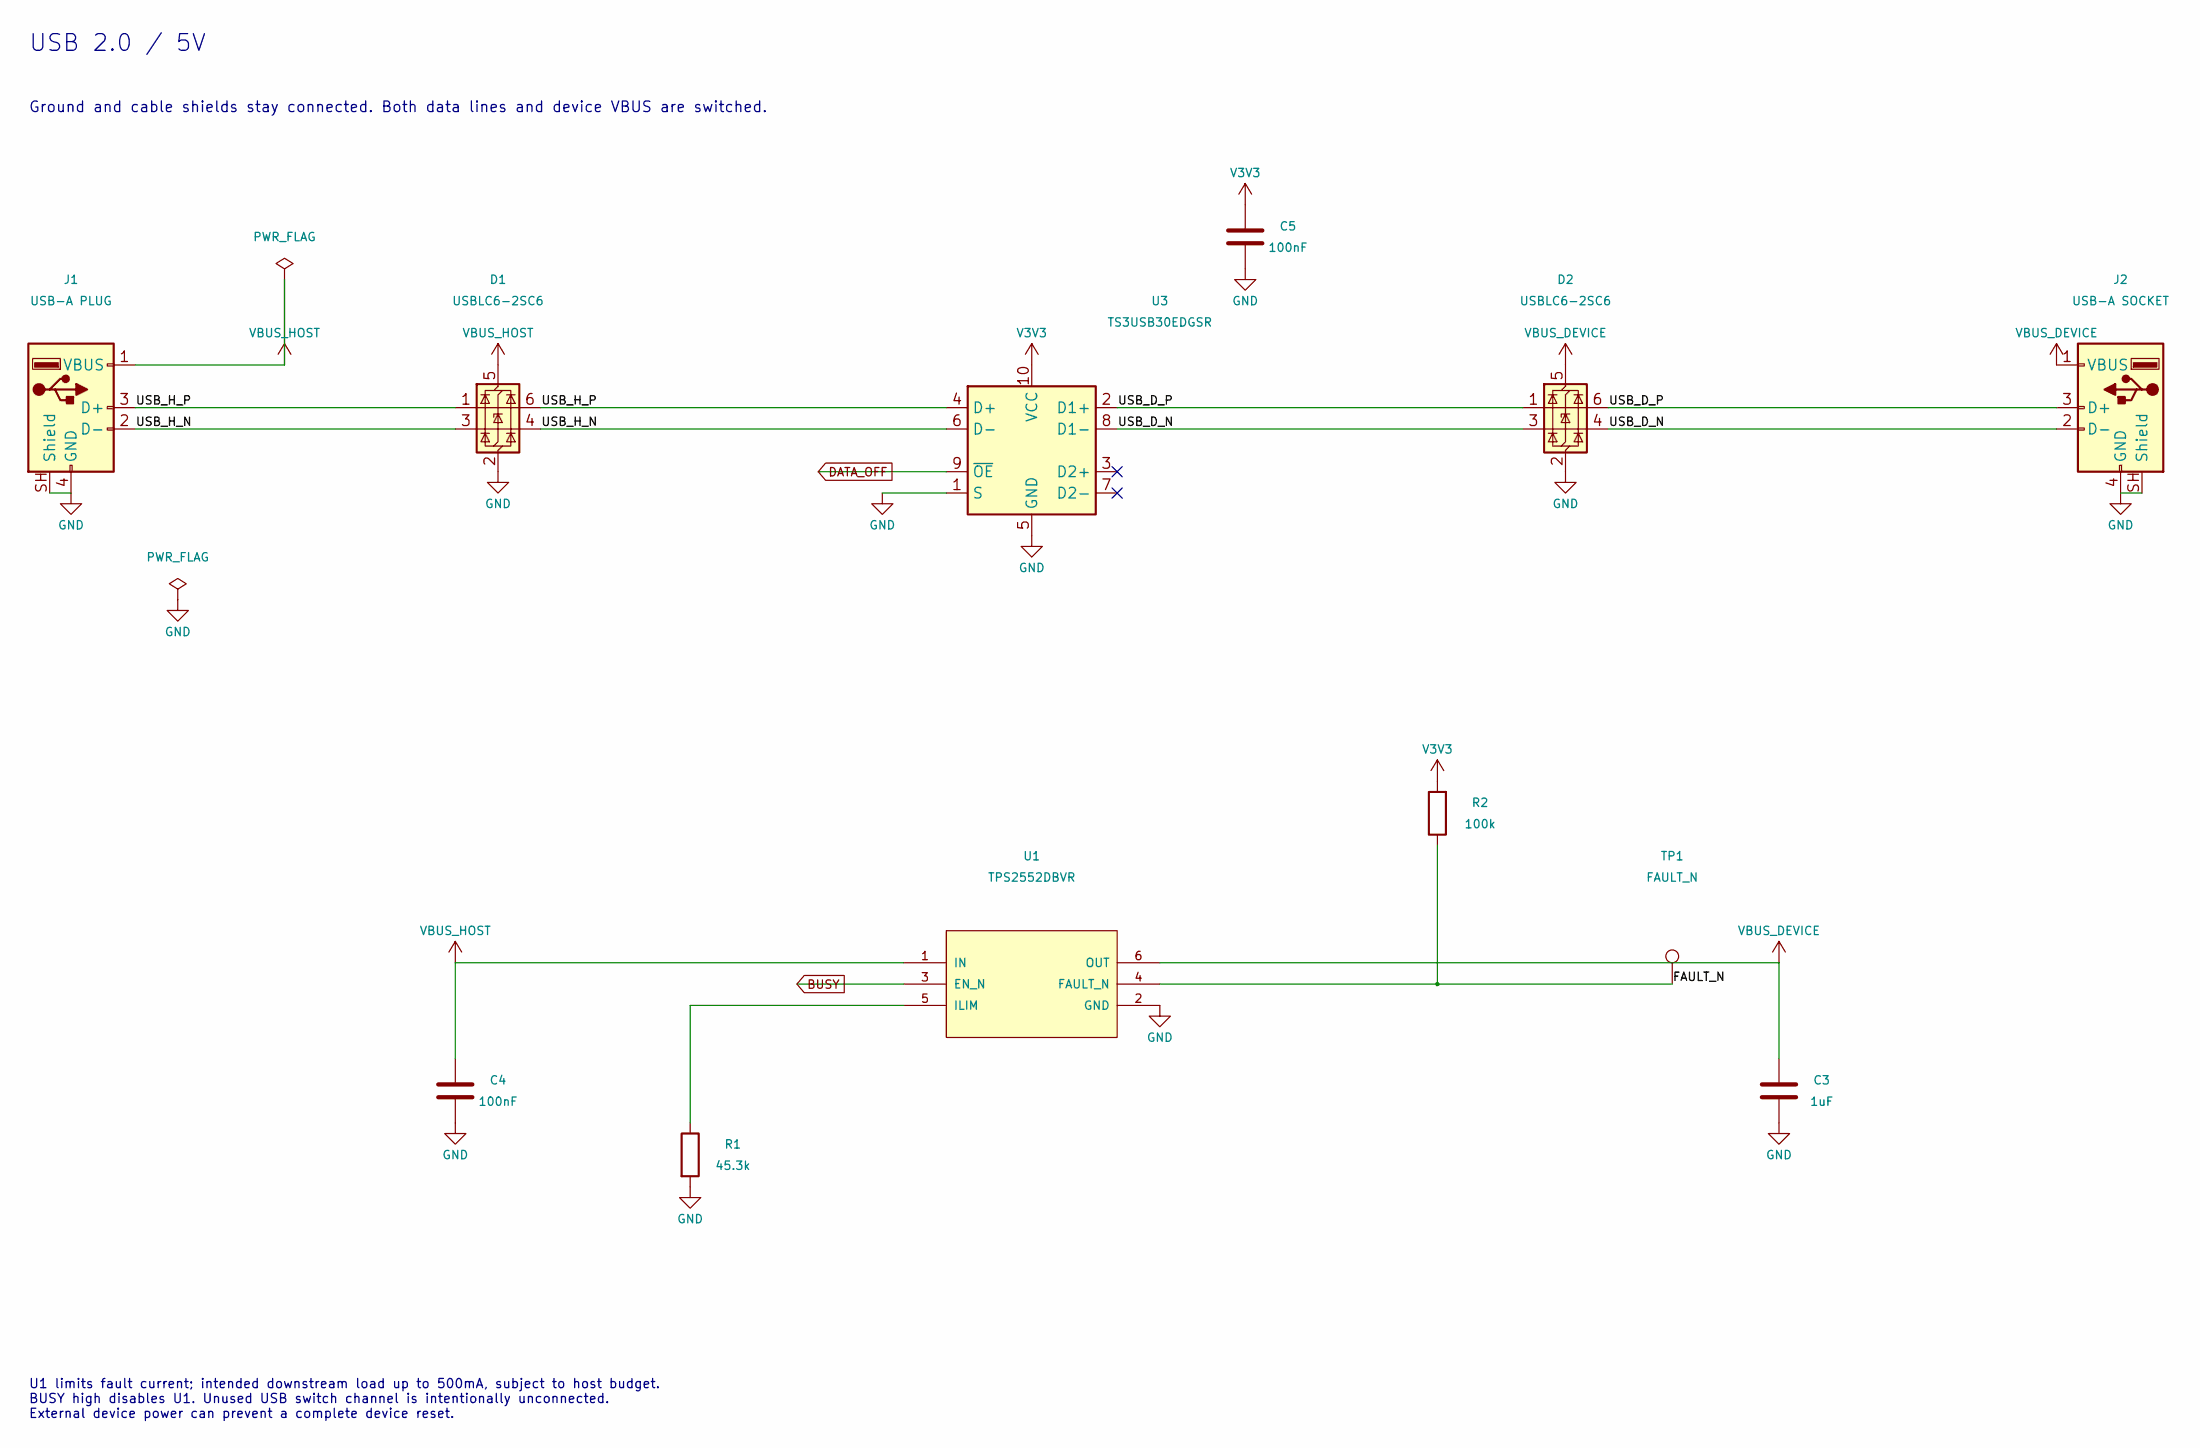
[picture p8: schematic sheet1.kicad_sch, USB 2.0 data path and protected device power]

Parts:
C3: 1uF; C_0603_1608Metric; MPN CL10A105KB8NNNC; LCSC C15849
C4, C5: 100nF; C_0603_1608Metric; MPN CC0603KRX7R9BB104; LCSC C14663
D1, D2: USBLC6-2SC6; SOT-23-6; MPN USBLC6-2SC6; LCSC C7519
J1: USB-A PLUG; USB_A_Molex_48037-2200_Horizontal; MPN 480372200; LCSC C2765195
J2: USB-A SOCKET; Jingtuo_902-131A1011D10100; MPN 902-131A1011D10100; LCSC C2345
R1: 45.3k; R_0603_1608Metric; MPN RC0603FR-0745K3L; LCSC C245971
R2: 100k; R_0603_1608Metric; MPN 0603WAF1003T5E; LCSC C25803
TP1: FAULT_N; TestPoint_Pad_D1.5mm; MPN PCB pad
U1: TPS2552DBVR; SOT-23-6; MPN TPS2552DBVR; LCSC C46506
U3: TS3USB30EDGSR; MSOP-10_3x3mm_P0.5mm; MPN TS3USB30EDGSR; LCSC C131998

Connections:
/USB and protected power/FAULT_N: R2.1, TP1.1, U1.4 (FAULT_N)
/USB and protected power/USB_D_N: D2.3 (I/O2), D2.4 (I/O2), J2.2 (D-), U3.8 (D1-)
/USB and protected power/USB_D_P: D2.1 (I/O1), D2.6 (I/O1), J2.3 (D+), U3.2 (D1+)
/USB and protected power/USB_H_N: D1.3 (I/O2), D1.4 (I/O2), J1.2 (D-), U3.6 (D-)
/USB and protected power/USB_H_P: D1.1 (I/O1), D1.6 (I/O1), J1.3 (D+), U3.4 (D+)
BUSY: U1.3 (EN_N); also elsewhere on the board
DATA_OFF: U3.9 (~OE); also elsewhere on the board
GND: C3.2, C4.2, C5.2, D1.2 (GND), D2.2 (GND), J1.4 (GND), J1.SH (Shield), J2.4 (GND), J2.SH (Shield), R1.2, U1.2 (GND), U3.1 (S), U3.5 (GND); also elsewhere on the board
unnamed: R1.1, U1.5 (ILIM)
V3V3: C5.1, R2.2, U3.10 (VCC); also elsewhere on the board
VBUS_DEVICE: C3.1, D2.5 (VBUS), J2.1 (VBUS), U1.6 (OUT); also elsewhere on the board
VBUS_HOST: C4.1, D1.5 (VBUS), J1.1 (VBUS), U1.1 (IN); also elsewhere on the board

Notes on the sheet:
USB 2.0 / 5V
Ground and cable shields stay connected. Both data lines and device VBUS are switched.
U1 limits fault current; intended downstream load up to 500mA, subject to host budget. BUSY high disables U1. Unused USB switch channel is intentionally unconnected. External device power can prevent a complete device reset.

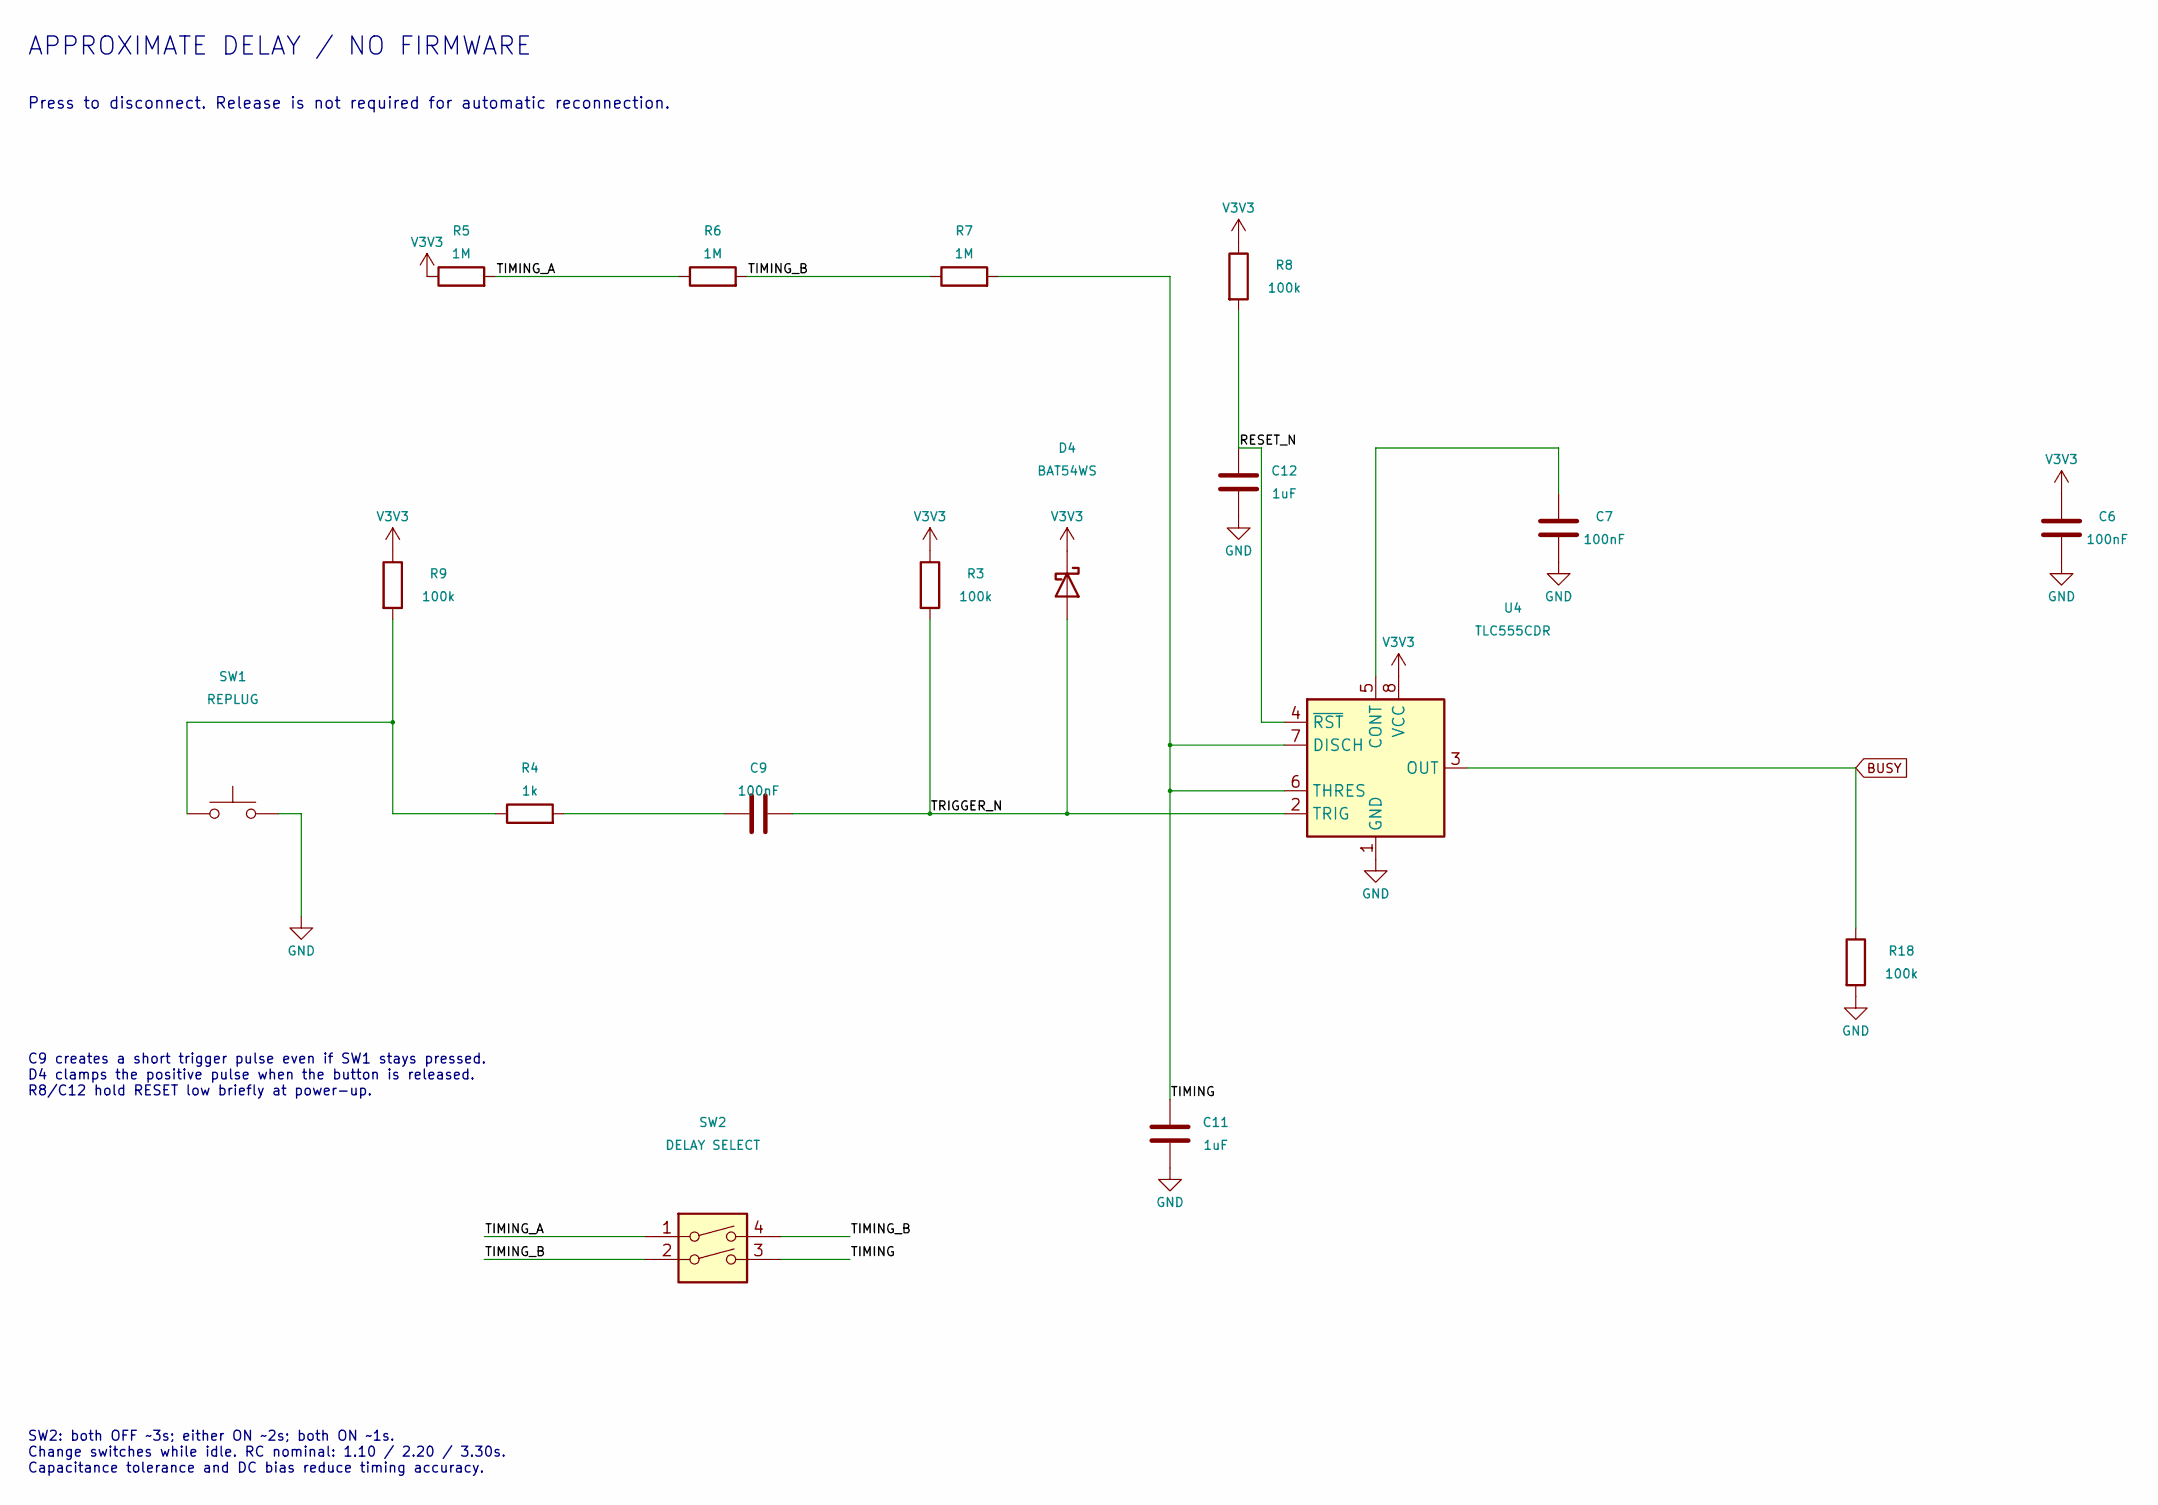
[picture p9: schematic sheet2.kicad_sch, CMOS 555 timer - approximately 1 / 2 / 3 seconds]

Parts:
C6, C7, C9: 100nF; C_0603_1608Metric; MPN CC0603KRX7R9BB104; LCSC C14663
C11, C12: 1uF; C_0603_1608Metric; MPN CL10A105KB8NNNC; LCSC C15849
D4: BAT54WS; D_SOD-323; MPN BAT54WS-7-F; LCSC C124205
R3, R8, R9, R18: 100k; R_0603_1608Metric; MPN 0603WAF1003T5E; LCSC C25803
R4: 1k; R_0603_1608Metric; MPN 0603WAF1001T5E; LCSC C21190
R5, R6, R7: 1M; R_0603_1608Metric; MPN 0603WAF1004T5E; LCSC C22935
SW1: REPLUG; SW_SPST_PTS645Sx43SMTR92; MPN PTS645SM43SMTR92 LFS; LCSC C221880
SW2: DELAY SELECT; SHOUHAN_1.27-2P_TPPT; MPN 1.27-2P TPPT; LCSC C7421516
U4: TLC555CDR; SOIC-8_3.9x4.9mm_P1.27mm; MPN TLC555CDR; LCSC C6986

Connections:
/555 hardware timer/RESET_N: C12.1, R8.2, U4.4 (~RST)
/555 hardware timer/TIMING: C11.1, R7.2, SW2.3, U4.6 (THRES), U4.7 (DISCH)
/555 hardware timer/TIMING_A: R5.2, R6.1, SW2.1
/555 hardware timer/TIMING_B: R6.2, R7.1, SW2.2, SW2.4
/555 hardware timer/TRIGGER_N: C9.2, D4.2 (A), R3.2, U4.2 (TRIG)
BUSY: R18.1, U4.3 (OUT); also elsewhere on the board
GND: C6.2, C7.2, C11.2, C12.2, R18.2, SW1.2, U4.1 (GND); also elsewhere on the board
unnamed: C9.1, R4.2
unnamed: R4.1, R9.2, SW1.1
unnamed: C7.1, U4.5 (CONT)
V3V3: C6.1, D4.1 (K), R3.1, R5.1, R8.1, R9.1, U4.8 (VCC); also elsewhere on the board

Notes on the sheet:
APPROXIMATE DELAY / NO FIRMWARE
Press to disconnect. Release is not required for automatic reconnection.
SW2: both OFF ~3s; either ON ~2s; both ON ~1s. Change switches while idle. RC nominal: 1.10 / 2.20 / 3.30s. Capacitance tolerance and DC bias reduce timing accuracy.
C9 creates a short trigger pulse even if SW1 stays pressed. D4 clamps the positive pulse when the button is released. R8/C12 hold RESET low briefly at power-up.

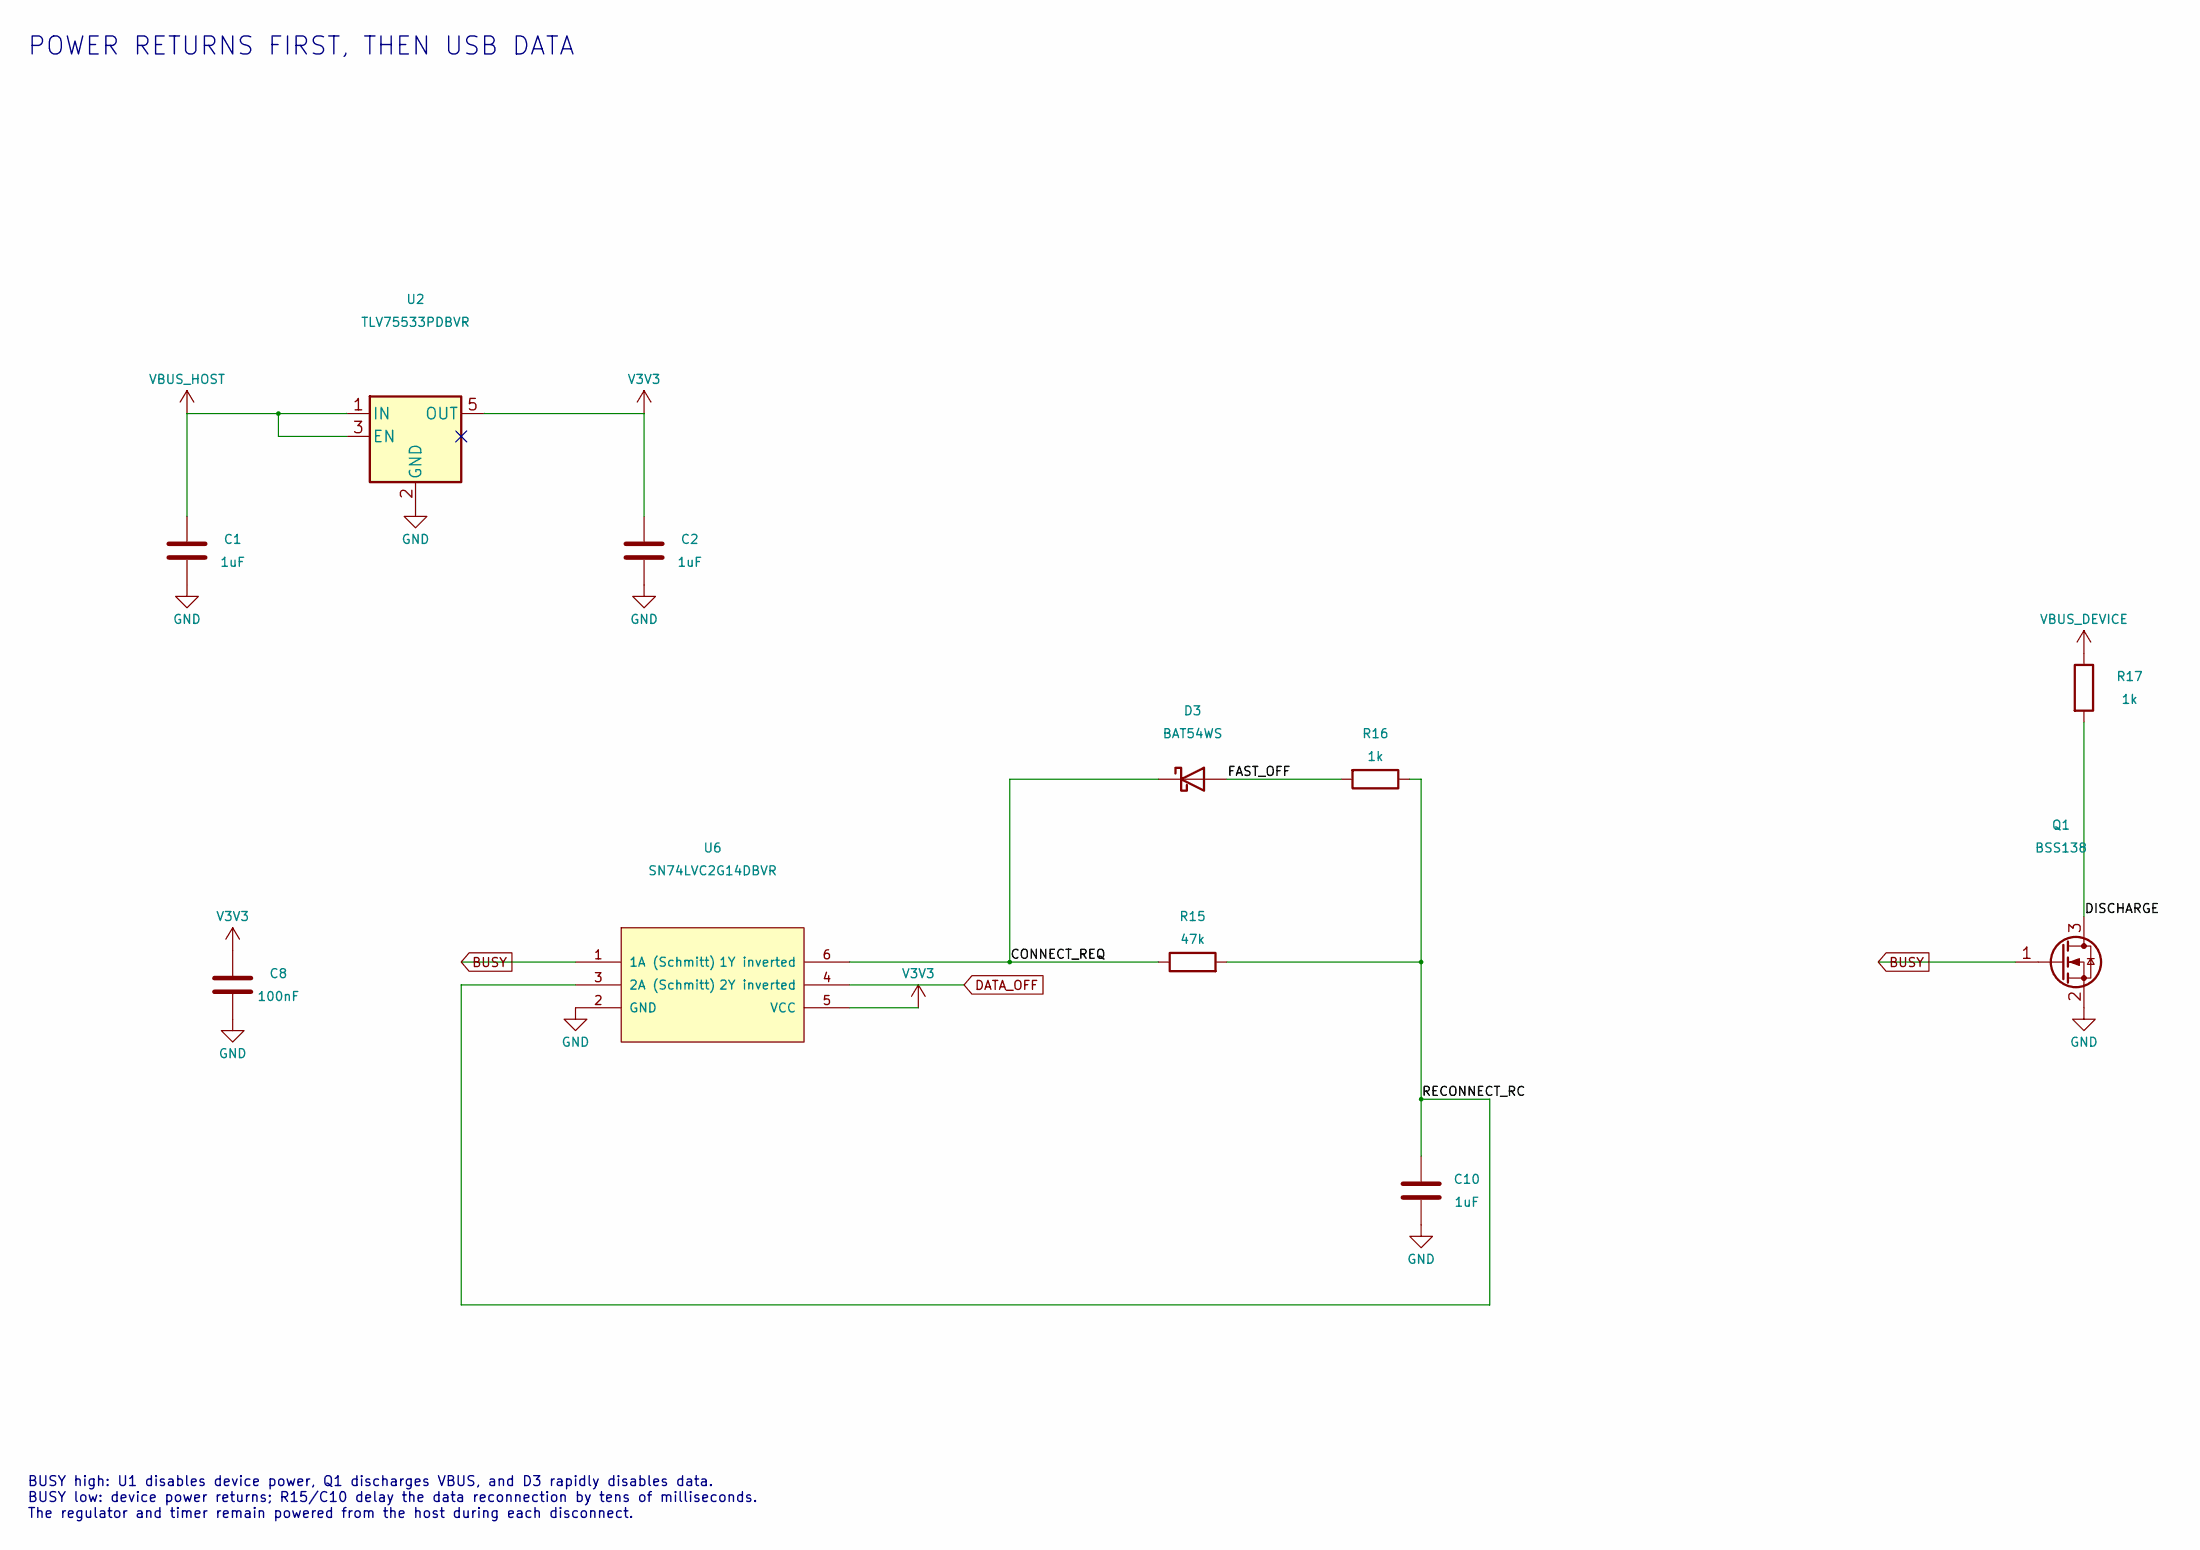
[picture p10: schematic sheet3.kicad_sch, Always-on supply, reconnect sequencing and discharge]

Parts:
C1, C2, C10: 1uF; C_0603_1608Metric; MPN CL10A105KB8NNNC; LCSC C15849
C8: 100nF; C_0603_1608Metric; MPN CC0603KRX7R9BB104; LCSC C14663
D3: BAT54WS; D_SOD-323; MPN BAT54WS-7-F; LCSC C124205
Q1: BSS138; SOT-23; MPN BSS138LT1G; LCSC C82045
R15: 47k; R_0603_1608Metric; MPN 0603WAF4702T5E; LCSC C25819
R16, R17: 1k; R_0603_1608Metric; MPN 0603WAF1001T5E; LCSC C21190
U2: TLV75533PDBVR; SOT-23-5; MPN TLV75533PDBVR; LCSC C404027
U6: SN74LVC2G14DBVR; SOT-23-6; MPN SN74LVC2G14DBVR; LCSC C12401

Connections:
/Supply and sequencing/CONNECT_REQ: D3.1 (K), R15.1, U6.6 (1Y inverted)
/Supply and sequencing/DISCHARGE: Q1.3 (D), R17.2
/Supply and sequencing/FAST_OFF: D3.2 (A), R16.2
/Supply and sequencing/RECONNECT_RC: C10.1, R15.2, R16.1, U6.3 (2A (Schmitt))
BUSY: Q1.1 (G), U6.1 (1A (Schmitt)); also elsewhere on the board
DATA_OFF: U6.4 (2Y inverted); also elsewhere on the board
GND: C1.2, C2.2, C8.2, C10.2, Q1.2 (S), U2.2 (GND), U6.2 (GND); also elsewhere on the board
V3V3: C2.1, C8.1, U2.5 (OUT), U6.5 (VCC); also elsewhere on the board
VBUS_DEVICE: R17.1; also elsewhere on the board
VBUS_HOST: C1.1, U2.1 (IN), U2.3 (EN); also elsewhere on the board

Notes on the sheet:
POWER RETURNS FIRST, THEN USB DATA
BUSY high: U1 disables device power, Q1 discharges VBUS, and D3 rapidly disables data. BUSY low: device power returns; R15/C10 delay the data reconnection by tens of milliseconds. The regulator and timer remain powered from the host during each disconnect.

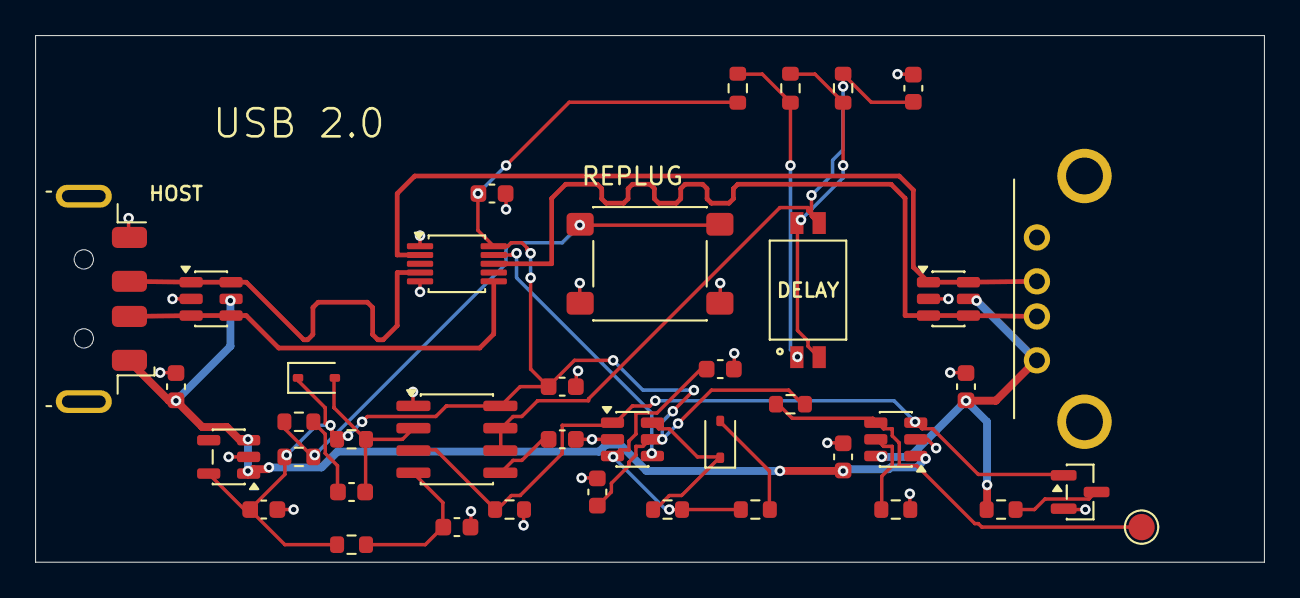
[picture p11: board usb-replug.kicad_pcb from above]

Board: 4 copper layers, 70.0 x 30.0 mm, 40 parts (0 on the bottom side), 24 nets.

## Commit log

2026-09-11 Add revision B for private prototype review
    [bom.csv, sheet1.kicad_sch, sheet2.kicad_sch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]
2026-09-11 Describe public prototype review and pending licensing work
